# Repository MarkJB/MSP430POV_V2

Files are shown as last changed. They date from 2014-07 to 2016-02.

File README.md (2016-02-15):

MSP430POV_V2
============

Revison 2 of the MSP430 based persistance of vision hardware.

The PCBs for this version are intended to be manufactured professionally.

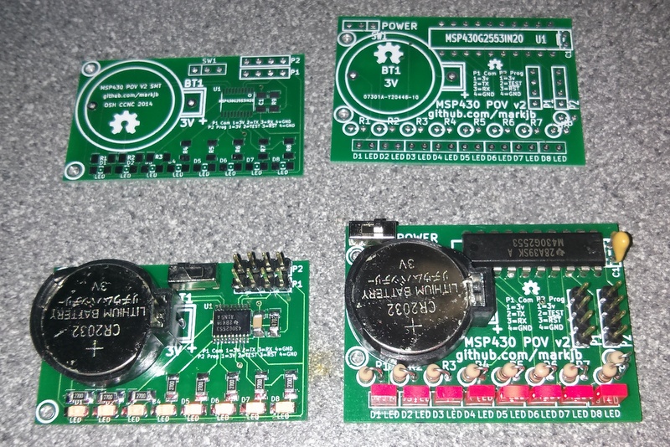
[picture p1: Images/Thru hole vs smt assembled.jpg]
MSP430PoV v2


================================HARDWARE=============================

22/07/2014 Received first batch of thru-hole PCBs. Assembled and tested board. When running on CR2302 works for about 30 seconds before locking up. Tried external 3V battery (2xAA) but exhibited same behaviour. Added 10uF cap. System locks up on CR2303 after about 30 seconds but runs fine on external 3V battery. Reflashed board (via P2 header connected to Launchpad) with current firmware and board set to 1MHz. Board now runs fine on CR2302. Need to determine if 10uF is necessary or if system is stable @ 1MHz without it.

To add a 1MHz board to Energia:

Add the follow to the boards.txt file in energia/hardware/msp430/boards.txt
```
##############################################################
lpmsp430g2553_1.name=LaunchPad w/ msp430g2553 (1MHz)
lpmsp430g2553_1.upload.protocol=rf2500
lpmsp430g2553_1.upload.maximum_size=16384
lpmsp430g2553_1.build.mcu=msp430g2553
lpmsp430g2553_1.build.f_cpu=1000000L
lpmsp430g2553_1.build.core=msp430
lpmsp430g2553_1.build.variant=launchpad
lpmsp430g2553_1.upload.maximum_ram_size=512
```
Restart Energia - check for extra board (Tools -> Boards)

28/07/2014 Received the first batch of SMT (surface mount) PCBs. Assembled and tested board without 10uF cap. Worked ok but two LEDs were out (P2.6 & P2.7). Checked LEDs and chip. Replaced chip. Same problem. Discovered that on blank chips the shared pins were in external xtal mode (P2.6 & P2.7 were set to xin and xout). Cleared the P2SEL register (setting all bits to zero) sets all pins to be port 2 input/outputs. 

Removed the 10uF cap from the thru-hole board and it works fine @ 1MHz. Don't think I need to alter the PCB to include it. Will need to see how well the boards perform as the battery voltage drops.

==========================FIRMWARE===================================

Master branch is the current stable v1.00 firmware.

It allows you to upload ASCII chars via serial. These messages are then stored in flash and will persist after power off.

If no message exists, the default pacman style ghost is displayed.

To upload ASCII messages, connect a serial terminal and power on and you will see info and a menu:
```
POV HW Rev 002 - firmware v1.00 - github.com/markjb/msp430pov_v2 - CCNC 2014
CPU Frequency = 1MHz
----------------------
Reading flash.........
Reading flash.....Done
----------------------
Commands (r)ead, (w)rite and (e)rase
```
Read  - will read the current content of the flash memory.
Erase - will erase the flash memory.
Write - will erase, write and read the flash memory.

You only need to use write as this will first call erase, then read, then write the message, then call read again.
```
w
----------------------
Erasing flash.........
Erasing flash.....Done
----------------------
Reading flash.........
Reading flash.....Done
----------------------
Commands (r)ead, (w)rite and (e)rase
----------------------
Write to flash........
Enter message to write to flash. Terminate string with a '.' (Message entry will timeout in 30 secs)
```
Type a message using the basic ASCII character set, end the message with a full stop (e.g. '.') and press return.
```
Hello World!.
Writing flash.........
Writing flash.....Done
----------------------
Reading flash.........
Reading flash.....Done
----------------------
Commands (r)ead, (w)rite and (e)rase
```
Extra debug output can be enabled by uncommenting the #define DEBUG lines in debug.h.

e.g. look for these lines and remove the //
```
//#define DEBUG1
//#define DEBUG2
//#define DEBUG_SLOWDOWN
```
DEBUG1 gives some extra info but should not interfere with normal operation.
DEBUG2 gives a lot more info and will slow down the led display. 
You will probably need to uncomment DEBUG_SLOWDOWN to add pauses between the debug statements.
Note: Debug adds about 2kb to the firmware size

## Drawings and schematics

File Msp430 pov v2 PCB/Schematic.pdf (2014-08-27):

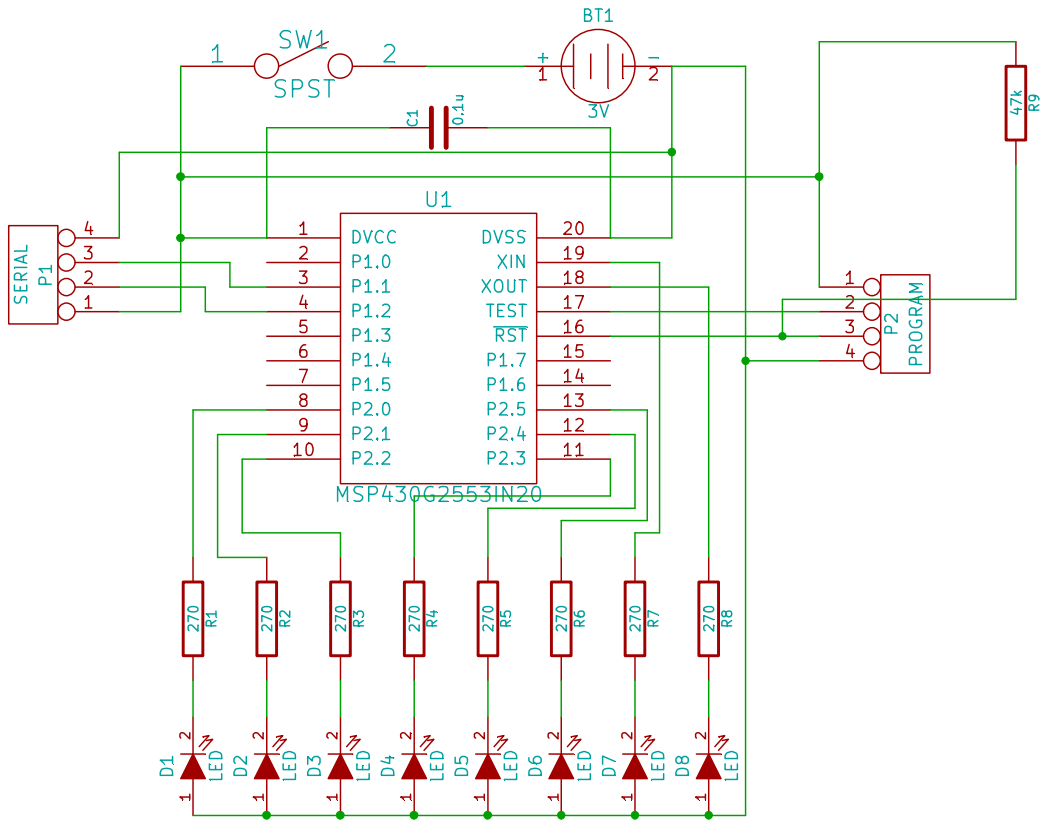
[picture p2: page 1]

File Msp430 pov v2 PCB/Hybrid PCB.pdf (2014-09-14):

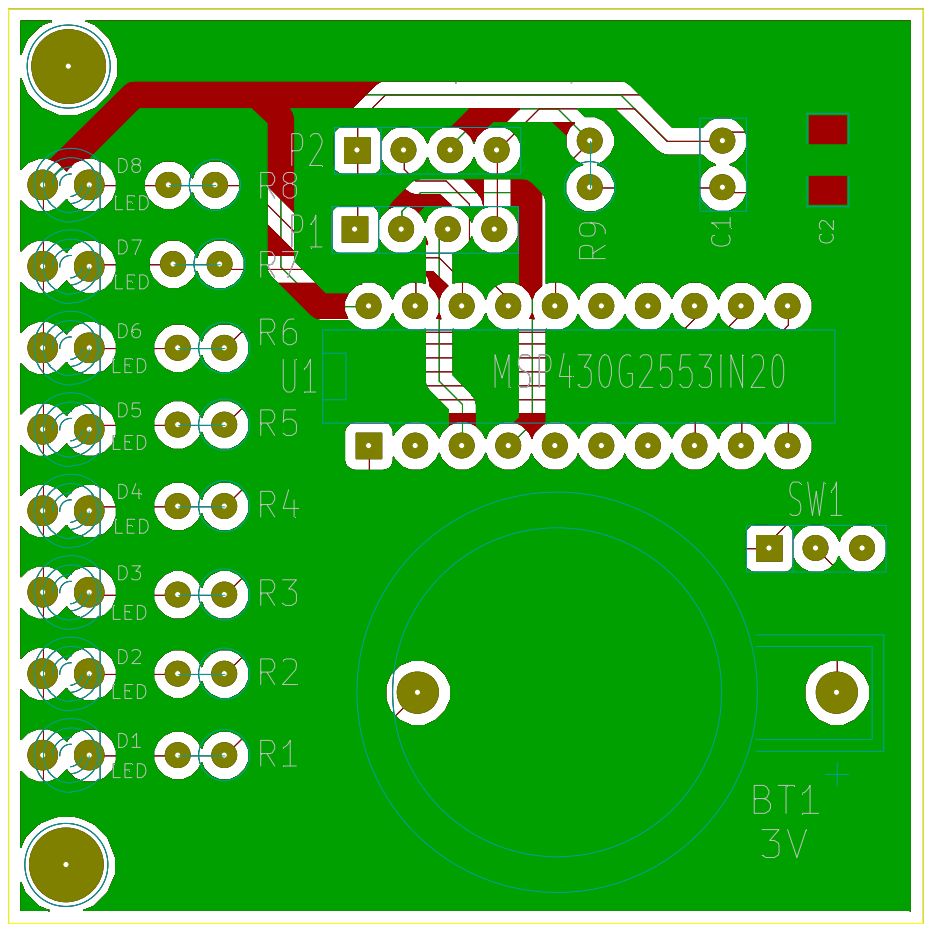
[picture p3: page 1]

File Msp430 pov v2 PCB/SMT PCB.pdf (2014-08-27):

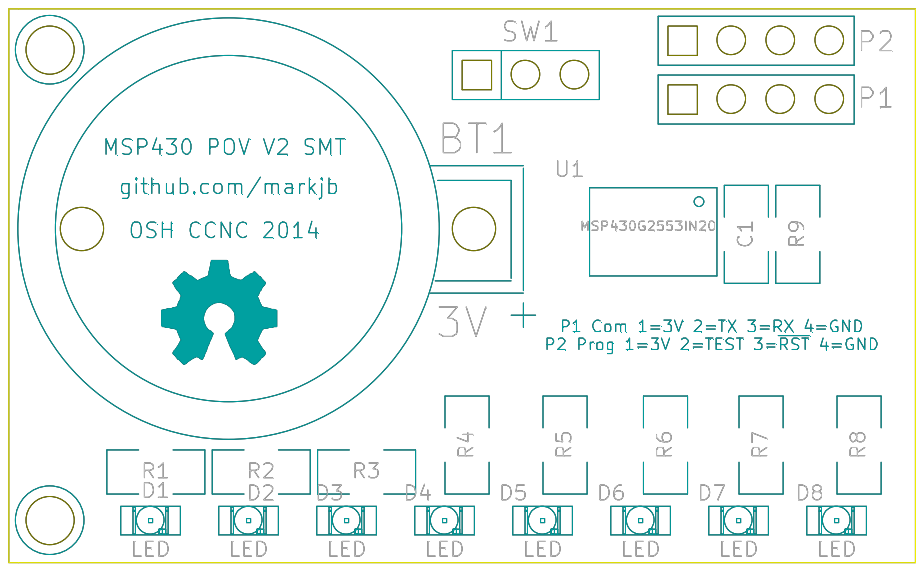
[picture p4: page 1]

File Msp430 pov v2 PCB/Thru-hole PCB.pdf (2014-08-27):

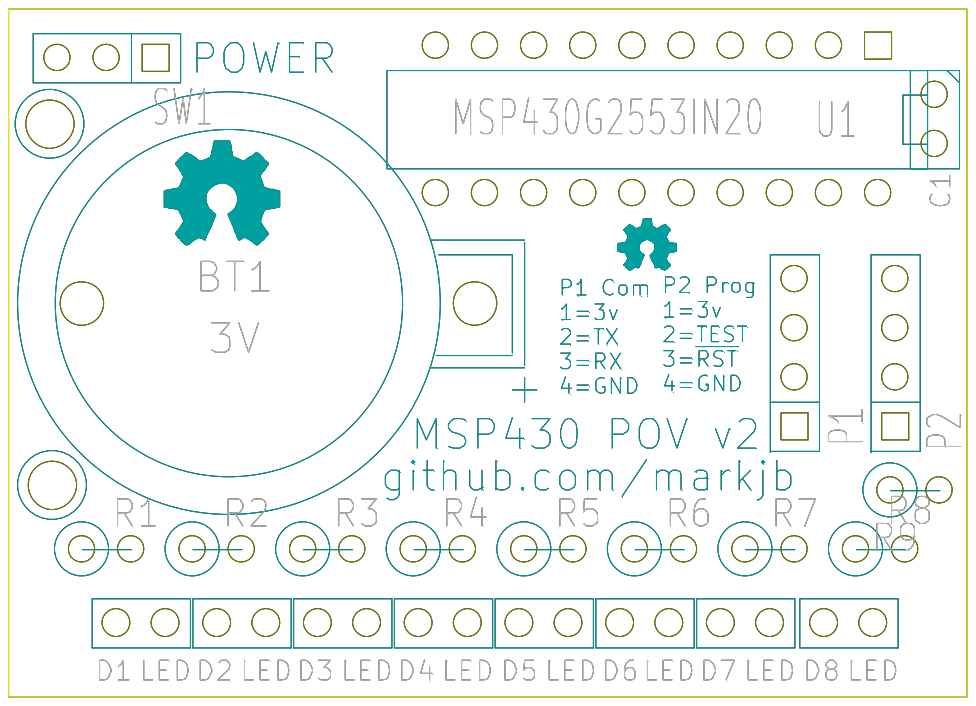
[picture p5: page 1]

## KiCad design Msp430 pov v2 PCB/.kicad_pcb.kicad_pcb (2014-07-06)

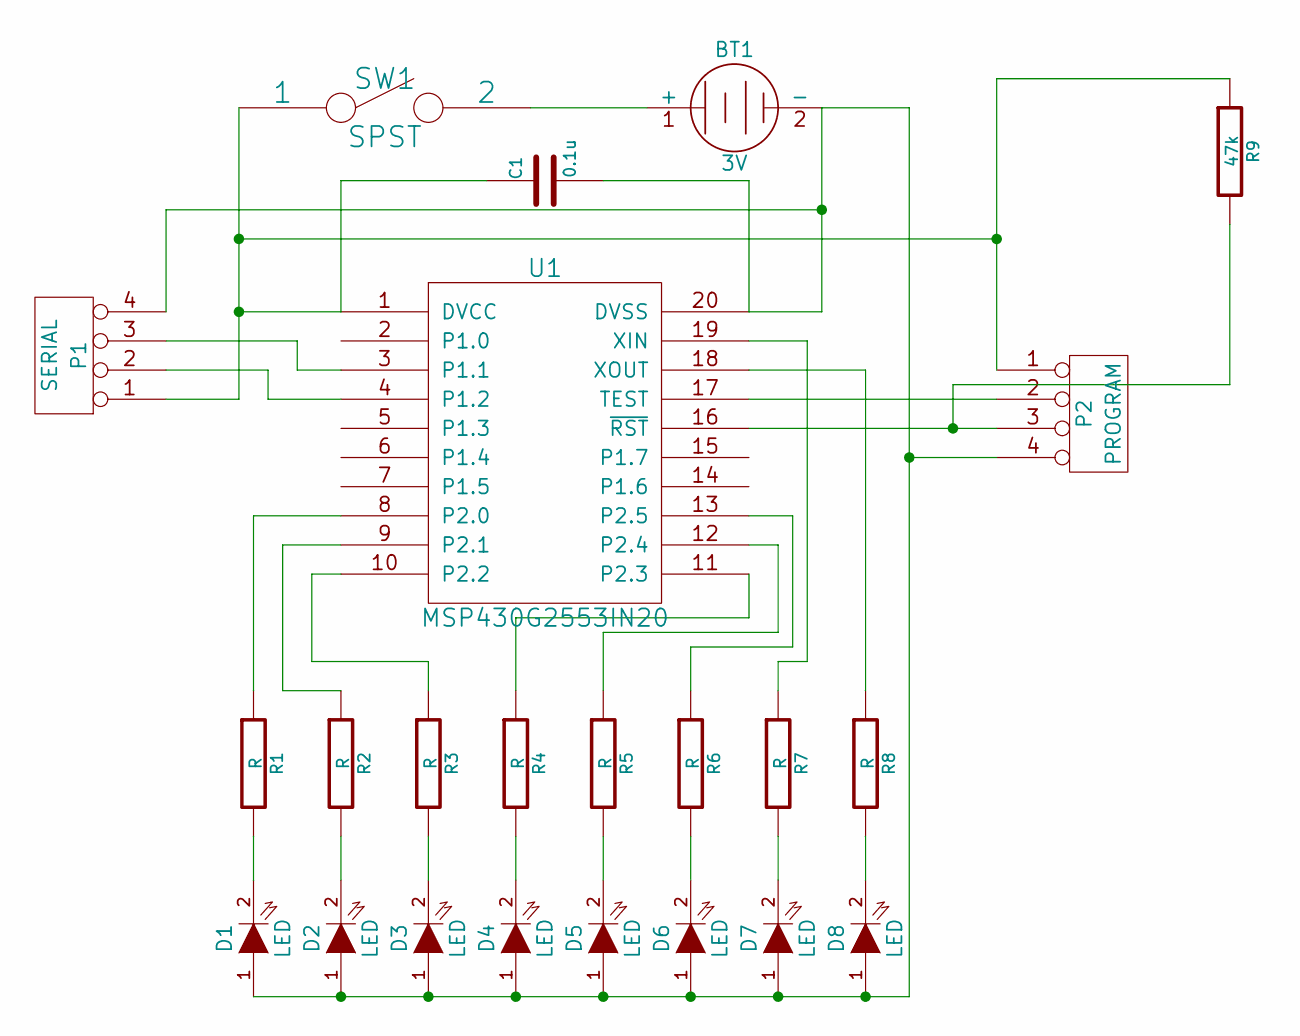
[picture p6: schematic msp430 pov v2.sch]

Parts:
BT1: 3V
C1: 0.1u
D1, D2, D3, D4, D5, D6, D7, D8: LED
P1: SERIAL
P2: PROGRAM
R1, R2, R3, R4, R5, R6, R7, R8: R
R9: 47k
SW1: SPST
U1: MSP430G2553IN20

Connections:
unnamed: R2.1, U1.9 (P2.1)
unnamed: R3.1, U1.10 (P2.2)
unnamed: R4.1, U1.11 (P2.3)
unnamed: R5.1, U1.12 (P2.4)
unnamed: R6.1, U1.13 (P2.5)
unnamed: R1.1, U1.8 (P2.0)
unnamed: D8.2 (K), R8.2
unnamed: D7.2 (K), R7.2
unnamed: D6.2 (K), R6.2
unnamed: P2.2, U1.17 (TEST)
unnamed: P2.3, R9.2, U1.16 (~RST)
unnamed: P1.2, U1.4 (P1.2)
unnamed: P1.3, U1.3 (P1.1)
unnamed: D5.2 (K), R5.2
unnamed: R8.1, U1.18 (XOUT)
unnamed: R7.1, U1.19 (XIN)
unnamed: D1.2 (K), R1.2
unnamed: BT1.1 (+), SW1.2
unnamed: D2.2 (K), R2.2
unnamed: D3.2 (K), R3.2
unnamed: D4.2 (K), R4.2
unnamed: C1.1, P1.1, P2.1, R9.1, SW1.1, U1.1 (DVCC)
unnamed: BT1.2 (-), C1.2, D1.1 (A), D2.1 (A), D3.1 (A), D4.1 (A), D5.1 (A), D6.1 (A), D7.1 (A), D8.1 (A), P1.4, P2.4, U1.20 (DVSS)

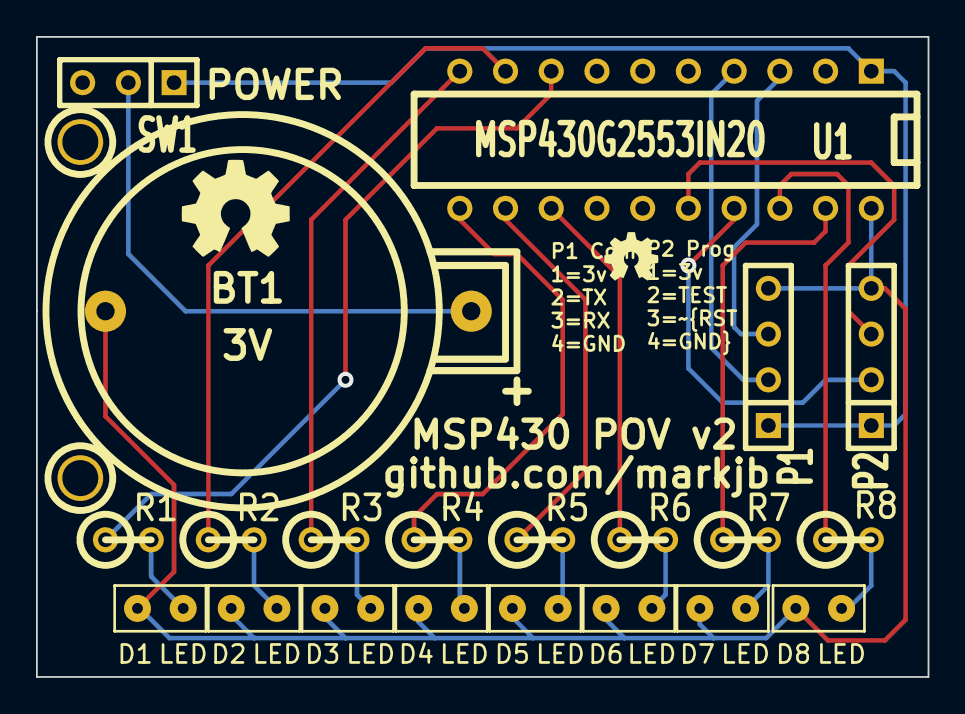
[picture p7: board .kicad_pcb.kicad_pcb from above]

Board: 2 copper layers, 49.5 x 35.6 mm, 23 parts (0 on the bottom side), 23 nets.

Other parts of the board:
1PIN, 1PIN#2: P***; 2mm

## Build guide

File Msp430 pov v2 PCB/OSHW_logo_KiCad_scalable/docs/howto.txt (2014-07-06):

How to make your own:
---------------------

Watch / read this first:

* http://www.kicad-pcb.org/display/KICAD/Videos+by+zupnikal

The last two videos should be helpful for how to create a custom .emp file from images.

* http://www.re-innovation.co.uk/web12/index.php/en/blog-75/230-adding-logo-to-kicad

If you use linux (which you should), you don't have to use the online-scaler. Just use the scripts!

---

* Create a folder to hold your new footprint library.
* Copy the scripts 'make_lib.sh' and 'scale.pl' into that folder.
* Make sure these files are executable (chmod u+x ...).
* Copy your custom .emp file into that foler.

* Run the 'make_lib.sh' script as follows:

./make_lib.sh input-file.emp lib-name.mod START END

START and END are placeholders for positive integer numbers (1,2,3...) that determine
the range of created footprint sizes. The units are metric (mm).

The 'lib-name.mod' file will show up in the 'lib' sub-folder. Add it to your pcbnew
library settings as usual.

Footprints that are created for back-layers are automagically mirrored horizontally.
To place them onto a back-layer, hover the mouse-pointer over them and press 'f' for 'flip'.

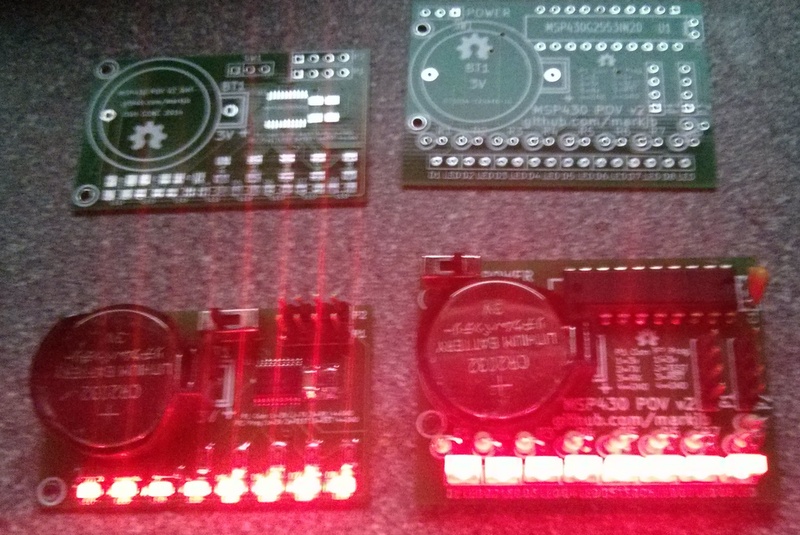
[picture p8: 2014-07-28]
Images/Thru hole vs smt assembled and working.jpg

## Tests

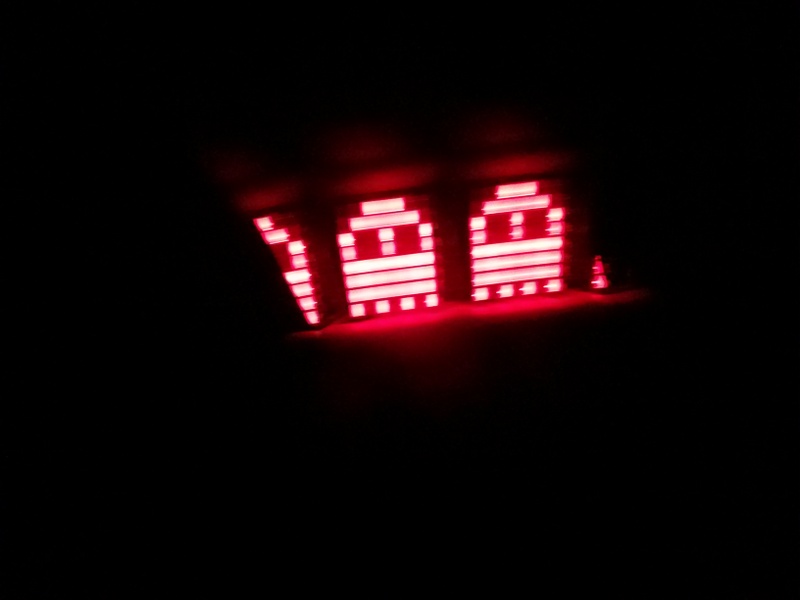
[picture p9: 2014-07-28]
Images/Thru hole POV test.jpg

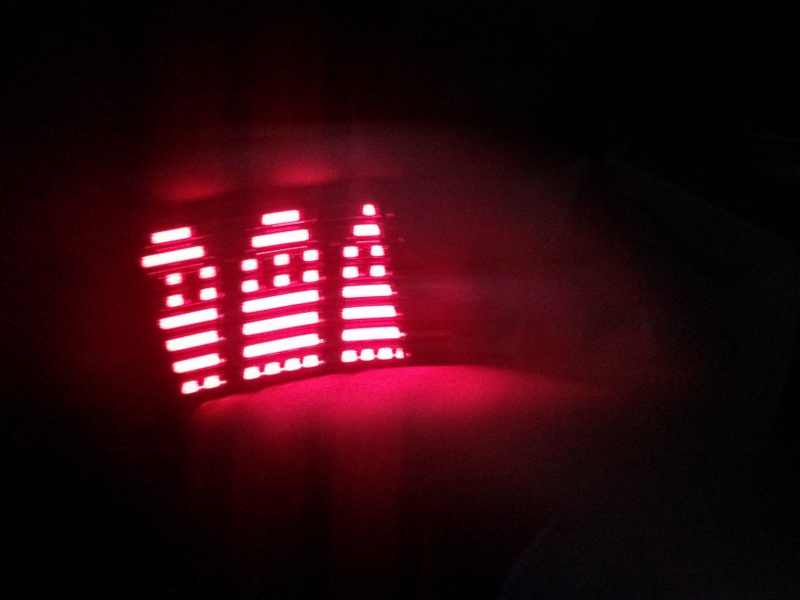
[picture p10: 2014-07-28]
Images/SMT POV test.jpg

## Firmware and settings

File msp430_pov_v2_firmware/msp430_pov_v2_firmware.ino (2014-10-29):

//MSP430 POV HW Rev2 firmware v1.00 - CCNC 2014
//
//Using the Energia IDE

//See debug.h for details of enabling or disabling the debug statements
//Saves about 2k of flash when all turned off
#include "debug.h"

//Include a fonts definition table - need to rewrite this from scratch
#include "fonts.h"

//Include lib to allow access to flash memory
#include "MspFlash.h"

//use one of the 64 byte info segments. Use SEGMENT_B, SEGMENT_C or SEGMENT_D (each 64 bytes, 192 bytes in total)
#define flash SEGMENT_D

//Byte arry
//PACMAN style ghost displayed by default

byte messageArray1[] = {
B00000000,
B00111111,
B01001110,
B11001111,
B11111110,
B11001111,
B01001110,
B00111111,
B00000000
};

//Array to hold ASCII message
char messageArray2[64];
int messageArray2Length = 0;

//Offset for font table - ASCII val - offset gives position in array that matches the ASCII value
int fontTableIndexOffset = 32;

//Define a pause value for use between led changes (value is in ms)
//Large values make characters appear wider, smaller values make them thinner.
//msg1 pause is for the default message routine.
//msg2 pause is for the ASCII message display routine
//Char spacing alters the gap between ASCII chars
int msg1PauseValue = 5;
int msg2PauseValue = 5;
int charSpacingPauseValue = 5;

void setup()
{
  //Enable serial comms
  Serial.begin(9600);
  
  //By default Port2 P2.6 & P2.7 are set as xin/xout to use external xtal
  //To use them as GPIO, set all port 2 pins as input/output here.
  P2SEL = B00000000;

  //enable pins out by port register
  // High = 1 = write
  P2DIR = B11111111;
  
  //Initalise output pins (they will hold a random value after a restart)
  //Set digital pins low
  P2OUT = B0;

  //If defined put in a delay
  DEBUG_SLOWDOWN_2;

  //Echo useful information at startup
  Serial.println("POV HW Rev 002 - firmware v1.00 - github.com/markjb/msp430pov_v2 - CCNC 2014");
  Serial.print("CPU Frequency = ");
  Serial.print((F_CPU/1000000));
  Serial.println("MHz");
  
  //Read in the message stored in flash
  DEBUG1_PRINTLN("Call doRead() to read flash memory");
  doRead();
  
}

void loop()
{
  //Main code to write the message array to the LEDs

  DEBUG2_PRINTLN("About to enter led printing loop");
  DEBUG_SLOWDOWN_1;

  //If there is no message data read from flash (i.e messageArray2Length = 0) then display
  //the default pacman ghost otherwise display the message retrived from flash
  
  DEBUG2_PRINTLN("Checking length of message array. If 0 then default else use messageArray2");
  DEBUG2_PRINT("messageArray2Length = ");
  DEBUG2_PRINTLN(int(messageArray2Length));
  
  if(messageArray2Length!=0)
  {
    //display messageArray2
    DEBUG2_PRINTLN("In display messageArray2 branch");
    
    //Loop thru messageArray2 one char at a time until there are no more left
    for(int x=0; x<messageArray2Length; x++)
    {
      DEBUG2_PRINTLN("In x part of messageArray2 led printing loop");
      DEBUG_SLOWDOWN_1;
      
      //Get the char value of the current char in the message
      char charToDisplay = messageArray2[x];
      byte byteToDisplay = byte(charToDisplay);
      
      //Include the offset value to make the ascii value match that of the font index array so we pick the right char
      byteToDisplay = byteToDisplay - fontTableIndexOffset;
      DEBUG2_PRINT("Current char has value :");
      DEBUG2_PRINTLN(byteToDisplay);   
      
      //Write a blank line before any char to give space between letters
      P2OUT = 0;
      delay(charSpacingPauseValue);
      
      //Write out each line of the current char
      for(int y=0; y<5; y++)
      {
         DEBUG2_PRINTLN("In y part of messageArray2 led printing loop");
         DEBUG_SLOWDOWN_1;    
         
         //Get the byte to display from the fonts table and display it here.      
         DEBUG2_PRINT("Getting font data for font[");
         DEBUG2_PRINT(byteToDisplay);
         DEBUG2_PRINT("][");
         DEBUG2_PRINT(y);
         DEBUG2_PRINT("] from font table. Data = ");
         DEBUG2_PRINTLN(font[byteToDisplay][y]);
         DEBUG2_PRINTLN("About to output data to the leds");
         
         //This is where the data is written to the leds.
         P2OUT = font[byteToDisplay][y];
         delay(msg2PauseValue);
         
      }
    }
    
    //Check if we have a command waiting on the serial port
    DEBUG2_PRINTLN("Polling for serial data from message2 loop");
    pollForSerialCommand();
    
  }
  else
  {
    //display messageArray1 (pacman style ghost)
    DEBUG2_PRINTLN("In display messageArray1 branch");
    DEBUG2_PRINTLN("-------------------------------------------");
    DEBUG2_PRINTLN("About to display default pacman style ghost");
    
    //Loop thru messageArray1 one byte at a time until there are no more left
    for(int x=0; x<=sizeof(messageArray1); x++)
    {
      DEBUG2_PRINTLN("About to output messageArray1 data to the leds");
      DEBUG2_PRINT("Outputting: ");
      DEBUG2_PRINTLN(messageArray1[x]);
      
      //This is where the data is written to the leds.
      P2OUT = messageArray1[x];
      delay(msg1PauseValue);
      
    }
    
    //Check if we have a command waiting on the serial port
    DEBUG2_PRINTLN("Polling for serial data from default message loop");
    pollForSerialCommand(); 
    
  }
  
}

void pollForSerialCommand()
{
  //Read input from serial and call functions if char is a valid command
  DEBUG2_PRINTLN("In pollForSerialCommand()");
  if ( Serial.available() )
  {
    switch ( Serial.read() )
    { 
      case 'e': doErase(); break;  
      case 'r': doRead(); break; 
      case 'w': doWrite(); break; 
      case 10:
      case 13: break;
      default: doHelp();
    }
  } 
}

void doRead()
{
  DEBUG1_PRINTLN("In doRead()");
  
  Serial.println("----------------------");
  Serial.println("Reading flash.........");
  
  DEBUG2_PRINT("Length currently stored in messageArray2Length = ");
  DEBUG2_PRINTLN(messageArray2Length);

  unsigned char p = 0;
  int i=0;
    
  do
  {
    Flash.read(flash+i, &p, 1);
    
    DEBUG2_WRITE(p);
    DEBUG2_PRINT(":");   
    DEBUG2_PRINTLN(p);
    DEBUG2_PRINT("Using the Flash.read() var i which is currently = ");
    DEBUG2_PRINTLN(i);

    messageArray2Length = i;
    messageArray2[i]=p;
  } while ( p && byte(p) < 255 && (i++ < 64) );
  
  DEBUG1_PRINTLN("Reached end of message in flash segment");
  DEBUG1_PRINT("Length of message read from flash (messageArray2Length) = ");
  DEBUG1_PRINTLN(messageArray2Length);
  
  //echo back the message now stored in messageArray2 (read from flash)
  DEBUG1_PRINT("messageArray2[] now contains: '");
  
  for(int x=0; x<messageArray2Length; x++)
  {
    DEBUG1_PRINT(messageArray2[x]);
  }
  DEBUG1_PRINTLN("'");
  
  Serial.println("Reading flash.....Done");
  Serial.println("----------------------");
  
  DEBUG_SLOWDOWN_2;
  
  Serial.println("Commands (r)ead, (w)rite and (e)rase");
}



void doErase()
{
  DEBUG1_PRINTLN("In doErase()");
  
  Serial.println("----------------------");
  Serial.println("Erasing flash........."); 
  
  Flash.erase(flash); 
  
  Serial.println("Erasing flash.....Done"); 
 
  DEBUG1_PRINTLN("Erasing ram..........."); 
  
  //Blank the current message in ram so we don't accidentally store random chars in flash
  for(int x=0; x<=sizeof(messageArray2); x++)
  {
    messageArray2[x]=' ';
  }
  
  DEBUG1_PRINTLN("Erasing ram.......Done");
  DEBUG1_PRINTLN("Verifying flash.......");
  
  doRead();
  
  DEBUG1_PRINTLN("Verifying flash...Done");
  DEBUG_SLOWDOWN_2;
}

void doWrite()
{
  //Store a message read in from the serial port or from flash memory at power on
  
  DEBUG1_PRINTLN("In doWrite()");
    
  //Erase flash before a write (can't write a 1 to flash memory, if it is set to zero it can't be set back unless you erase it)
  
  doErase();
  
  Serial.println("----------------------");
  Serial.println("Write to flash........");
  Serial.println("Enter message to write to flash. Terminate string with a '.' (Message entry will timeout in 30 secs)");
  
  //Not used at the moment - need to decide if we need a better terminator char
  //int termChar = 10;
  
  Serial.flush();
  Serial.setTimeout(30000);
  
  DEBUG1_PRINTLN("About to readBytesUntil() from serial port");
  
  int messageArray2Length = Serial.readBytesUntil('.', messageArray2, 64);
  
  DEBUG1_PRINT("Length returned by readBytesUntil=");
  DEBUG1_PRINTLN(messageArray2Length);
  DEBUG1_PRINTLN("Done with readBytesUntil");
 
  //echo back the whole byte array ignoring message length
  DEBUG1_PRINTLN("Array contains:");
 
  for(int x=0; x<=sizeof(messageArray2); x++)
  {
    DEBUG1_PRINT(messageArray2[x]);
  }
  
  DEBUG1_PRINTLN("");
  
  
  Serial.println("Writing flash.........");
  
  Flash.write(flash, (unsigned char*) messageArray2 , messageArray2Length); 
  
  Serial.println("Writing flash.....Done");
  
  DEBUG1_PRINTLN("Reading back message from flash to populate variables (doRead() called from doWrite())");
  
  doRead();
  
  DEBUG1_PRINTLN("Reading back message from flash to populate variables... Done.");
  DEBUG1_PRINTLN("exiting doWrite()");
  DEBUG_SLOWDOWN_2;
}

void doHelp()
{
  DEBUG1_PRINTLN("In doHelp()");
  Serial.println("Commands (r)ead, (w)rite and (e)rase");
}

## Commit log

2014-07-06 Commit initial files
    Version 2 PCB kicad files and gerbers and basic firmware created in
    Energia
    [$msp430 pov v2.sch, .kicad_pcb.kicad_pcb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]
2014-07-28 Firmware update to set mode of shared pins
    On a blank chip the shared pins P2.6 & P2.7 were set to xin/xout. Needed
    to set all pins on port2 into output mode with P2SEL register.
    [$msp430 pov v2.sch, msp430 pov v2.sch]
2014-07-28 Updates for SMT boards
    Updates to firmware and readme. SMT PCBs have not changed
2014-07-28 Added pictures of boards
    Pictures of SMT and Thru-hole boards assembled and tested.
2014-07-28 Update README
    Added TODO: reminder to add infill on PCBs.
2014-08-27 PDFs of PCBs and Schematic
    Added PDFs of Schematic and SMT & thru-hole PCBs as its a pain in the
    arse when you want to look at them on github and don't have the right
    software installed.
2014-09-14 extras
    Added a hybrid board for an kids soldering class. Includes a single
    redundant 1206 SMT cap as a first step in soldering SMT.
    Added the boards.txt file for Energia. This file includes the 1MHz G2553
    chip config.
    Cleaned up the basic test firmware.
2014-09-16 Write to/Read from flash working. Fonts lib included
    Code to erase/write/read flash working.
    Added fonts.h to convert ASCII to POV data.
    This was working for a little while on the smt rev2 board, but then it
    stopped working, can't input a message, serial comms routine isn't
    working. Have shifted the code around but no dice...
2014-10-29 Changed fonts.h
    Removed existing fonts.h and added one created from scratch. Font design
    files included.
    Also flipped default 'Pacman' style ghost to match new font.
    [msp430_pov_v2_firmware.ino]
